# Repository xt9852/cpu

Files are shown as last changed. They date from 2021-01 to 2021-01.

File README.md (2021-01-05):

# 项目说明
- 这是一个用TTL与非门电路自制CPU项目
- 微指令结构
- 8位数据总线(BD)
- 8位地址总线(BA)
- 9个8位寄存器(RI,RF,RP,RS,RA,RB,RC,RD,RT)
- 1个8位ALU
- 目前只用Proteus做模拟

# 项目文件
|文件|说明|
|----|----|
|8bit-cpu.dsn|Proteus的模拟|
|8bit-cpu.LYT|Proteus的PCB|
|16bit-cpu.dsn|Proteus的模拟|
|doc/cpu.png|cpu逻辑架构图|
|doc/make pcb.txt|将ares转为CAM350步骤|
|doc/mi.xls|微指令详细|
|mi/mi.exe|生成微指令工具,将mi.txt转化成mi_*.bin|
|mi/MI.c|mi.exe的源代码|
|mi/mi.txt|微指令源码|
|mi/mi_*.bin|微指令|
|mi/rom.bin|内存程序|

# 逻辑结构
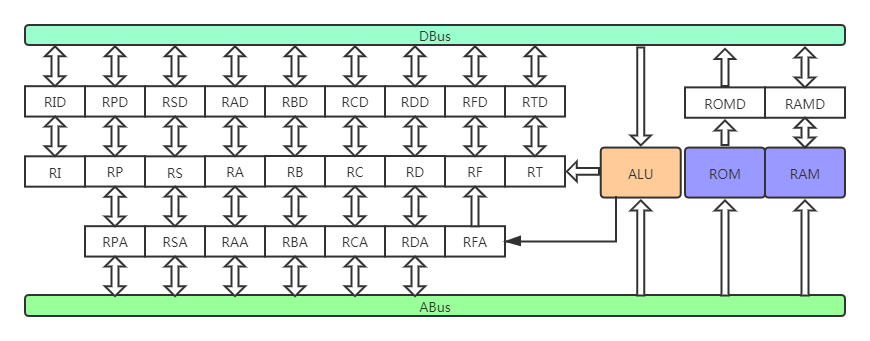
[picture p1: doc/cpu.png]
cmd-markdown-logo


# 物理结构
- 微指令驱动部分
    由AN0-1,AC0-1组成,
    由IN-CLK,SIG-CLK_信号驱动,
    主要是对微指令的当前地址进行操作

- 微指令跳转部分
    由SEL0-5组成,
    由IN-INT0-1,CHK-BI,JL,JNE信号生成的SIG-A,SIG-B信号驱动,
    主要是对微指令的下一条地址进行操作,
    通过选择不同的微指令地址以实现微指令跳转

    |SIG-B|SIG-A|说明|
    |----|----|----|
    |0|0|选取下一条地址为微指令地址|
    |0|1|选取0x[BI]0组成微指令地址|
    |1|0|选取中断微指令地址0x005|
    |1|1|选取条件跳转微指令地址0x004|
    
- 微指令存储部分
    由MI0~7组成，
    由AC[]驱动

    |微指令|说明|
    |----|----|
    |CHK-BI|选取指令寄存器做微指令地址|
    |CHK-INT|检测是否发生中断|
    |CHK-JE|检测是否等于跳转|
    |CHK-JNE|检测是否不等于跳转|
    |CHK-JB|检测是否大于跳转|
    |CHK-JBN|检测是否大于等于跳转|
    |CHK-JL|检测是否小于跳转|
    |CHK-JLN|检测是否小于等于跳转|
    |RA-A|连通A总线,0-输入,1-输出|
    |RA-RW|操作:0-读,1写|
    |RA-D|连通D总线,0-输入,1-输出|
    |ALU-S0|ALU控制S0|
    |ALU-S1|ALU控制S1|
    |ALU-S2|ALU控制S2|
    |ALU-S3|ALU控制S3|
    |ALU-M|ALU运算类型:0-算数,1-逻辑|
    |ALU-CN|ALU进位|
    |MEM-CE|内存选通|
    |MEM-RW|内存操作:0-读，1写|
    |MEM-OE|内存读操作:0-有效，1-无效|
    |MEM-WE|内存写操作:0-有效，1-无效|

- 寄存器与总线部分
    RI,RID,RF,RFA,RFD,RP,RPA,RPD,RS,RSA,RSD,
    RA,RAA,RAD,RB,RBA,RBD,RC,RCA,RCD,RD,RDA,RDD,
    RT,RTD

- ALU与临时寄存器部分
    由ALU0-1，RT组成,
    由ALU-S0-3,M,CN,RT-RW,RT-F信号驱动

- 内存部分
    由ROM,RAM,ROMD,RAMD组成,
    由BA,BD,MEM-CE,RW,OE,WE信号驱动

# 数据流
- 微指令跳转部分=>微指令驱动部分=>微指令存储部分=>寄存器与总线部分,ALU与临时寄存器部分,内存部分

# 指令执行过程
- 清空各寄存器操作
- 检测中断操作
- 取指和IP++操作
- 更新IP操作
- 执行指令操作

# 微代码说明
- [微代码详细](https://github.com/xt9852/CPU/blob/master/doc/mi.xls)

# 所用芯片
|芯片|说明|
|----|----|
|74LS04|非门|
|74LS08|2输入与门|
|74LS32|2输入或门|
|74LS138|3-8译码器|
|74LS153|双4选1选择器|
|74LS165|并入串出|
|74LS181|逻辑运算器|
|74LS245|双向驱动器|
|74LS373|寄存器|
|2732|ROM存储器,存储微指令|
|27256|ROM存储器|
|62256|RAM存储器|

# ALU逻辑
|S0|S1|S2|S3|M|Cn|功能|
|----|----|----|----|----|----|----|
|H|H|L|L|H|*|0|
|L|L|H|H|H|*|0xFF|
|H|H|H|H|H|*|A|
|H|L|H|L|H|*|B|
|L|L|L|L|H|*|A非|
|H|H|L|H|H|*|A与B|
|L|H|H|H|H|*|A或B|
|L|H|H|L|H|*|A异或B|
|H|L|L|H|L|H|A加B|
|L|H|H|L|L|L|A减B|
|L|L|L|L|L|L|A++|
|H|H|H|H|L|H|A--|

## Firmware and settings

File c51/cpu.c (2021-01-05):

//头文件:
#include <reg52.h>
#include <stdio.h>
#include "uart.h"    // 串口


// IO引脚定义
sbit DATA_IN  = P1^0;
sbit DATA_LD  = P1^1;
sbit DATA_CLK = P1^2;
sbit IN_CLK   = P1^3;

// 延时子函数,int为2个字节,long为4个字节
// 参数 time 大小决定延时时间长短
void delay(unsigned long n)
{
	n *= 10;

	while(n--); // 用于延时
}

void uart_proc(unsigned char ch, void *param)
{
    UART_send_byte(ch);
}

void save_data()
{
    DATA_LD = 0;    // save data
    delay(1);
    DATA_LD = 1;
    delay(1);
}

unsigned long get_data(unsigned int count)
{
    unsigned int i;
    unsigned long d;
    unsigned long n = 0;

    for (i = 0; i < count; i++)
    {
        d = DATA_IN;    // read data
        delay(1);
        DATA_CLK = 0;
        delay(1);
        DATA_CLK = 1;   // output data
        delay(1);
        
        n |= (d << i);
    }

    return n;
}

void get_mi()
{
    char buff[32];
    unsigned int i;
    unsigned int j;
    unsigned int k;
    unsigned int l;

    save_data();
    UART_send_string("--save--data--\r");
    
    i = get_data(12);
    sprintf(buff, "AC:      0x%03X\r", i);

    UART_send_string(buff);
    i = get_data(12);
    sprintf(buff, "AT:      0x%03X\r", i);
    UART_send_string(buff);

    i = get_data(12);
    sprintf(buff, "AN:      0x%03X\r", i);
    UART_send_string(buff);

    i = get_data(8);
    sprintf(buff, "BA:      0x%02X\r", i);
    UART_send_string(buff);

    i = get_data(8);
    sprintf(buff, "BD:      0x%02X\r", i);
    UART_send_string(buff);

    i = get_data(8);
    sprintf(buff, "BF:      0x%02X\r", i);
    UART_send_string(buff);

    i = get_data(1);
    sprintf(buff, "SIG-JL:  %d\r", i);
    UART_send_string(buff);

    i = get_data(1);
    sprintf(buff, "SIG-JNE: %d\r", i);
    UART_send_string(buff);

    i = get_data(2);
    sprintf(buff, "SIG-AB:  %d\r", i);
    UART_send_string(buff);

    i = get_data(1);
    sprintf(buff, "CHK-BI:  %d\r", i);
    UART_send_string(buff);

    i = get_data(1);
    sprintf(buff, "CHK-INT: %d\r", i);
    UART_send_string(buff);

    i = get_data(1);
    sprintf(buff, "CHK-JE:  %d\r", i);
    UART_send_string(buff);

    i = get_data(1);
    sprintf(buff, "CHK-JNE: %d\r", i);
    UART_send_string(buff);

    i = get_data(1);
    sprintf(buff, "CHK-JB:  %d\r", i);
    UART_send_string(buff);

    i = get_data(1);
    sprintf(buff, "CHK-JBE: %d\r", i);
    UART_send_string(buff);

    i = get_data(1);
    sprintf(buff, "CHK-JL:  %d\r", i);
    UART_send_string(buff);

    i = get_data(1);
    sprintf(buff, "CHK-JLE: %d\r", i);
    UART_send_string(buff);

    j = get_data(1);
    k = get_data(1);
    sprintf(buff, "RI:%s %s\r", (j==0?"R":"W"), (k==0?"DBus":""));
    UART_send_string(buff);

    i = get_data(1);
    j = get_data(1);
    k = get_data(1);
    sprintf(buff, "RF:%s %s %s\r", (j==0?"R":"W"), (k==0?"DBus":""), (i==0?"ABus":""));
    UART_send_string(buff);

    i = get_data(1);
    j = get_data(1);
    k = get_data(1);
    sprintf(buff, "RP:%s %s %s\r", (j==0?"R":"W"), (k==0?"DBus":""), (i==0?"ABus":""));
    UART_send_string(buff);

    i = get_data(1);
    j = get_data(1);
    k = get_data(1);
    sprintf(buff, "RS:%s %s %s\r", (j==0?"R":"W"), (k==0?"DBus":""), (i==0?"ABus":""));
    UART_send_string(buff);

    i = get_data(1);
    j = get_data(1);
    k = get_data(1);
    sprintf(buff, "RA:%s %s %s\r", (j==0?"R":"W"), (k==0?"DBus":""), (i==0?"ABus":""));
    UART_send_string(buff);


    i = get_data(1);
    j = get_data(1);
    k = get_data(1);
    sprintf(buff, "RB:%s %s %s\r", (j==0?"R":"W"), (k==0?"DBus":""), (i==0?"ABus":""));
    UART_send_string(buff);

    i = get_data(1);
    j = get_data(1);
    k = get_data(1);
    sprintf(buff, "RC:%s %s %s\r", (j==0?"R":"W"), (k==0?"DBus":""), (i==0?"ABus":""));
    UART_send_string(buff);


    i = get_data(1);
    j = get_data(1);
    k = get_data(1);
    sprintf(buff, "RD:%s %s %s\r", (j==0?"R":"W"), (k==0?"DBus":""), (i==0?"ABus":""));
    UART_send_string(buff);

    i = get_data(6);
    if (i == 0) sprintf(buff, "ALU:++\r");
    else if (i == 0x13) sprintf(buff, "ALU:0xFF\r", i);
    else if (i == 0x34) sprintf(buff, "ALU:0xFF\r", i);
    else sprintf(buff, "ALU:%x\r", i);
    UART_send_string(buff);

    j = get_data(1);
    k = get_data(1);
    sprintf(buff, "RT:%s %s\r", (j==0?"R":"W"), (k==0?"DBus":""));
    UART_send_string(buff);

    i = get_data(1); // M-CE
    j = get_data(1); // M-RW
    k = get_data(1); // M-OE
    l = get_data(1); // M-WE
    sprintf(buff, "MEM:%s OE:%d WE:%d\r", (i==0?(j==0?"R":"W"):""), j, k);
    UART_send_string(buff);

    i = get_data(1); // SIG-ROM
    sprintf(buff, "SIG-ROM:%d\r", i);
    UART_send_string(buff);

    i = get_data(1); // SIG-RAM
    sprintf(buff, "SIG-RAM:%d\r", i);
    UART_send_string(buff);
}

//主函数，C语言的入口函数
void main(void)
{
    unsigned int last = 1;

    UART_init(2400, uart_proc, '\n');

    while (1)
	{
        if (last == 1 && IN_CLK == 0)
        {
             get_mi();
        }

        last = IN_CLK;

        delay(10);
	}
}

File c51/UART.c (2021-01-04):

#include <reg52.h>
#include "UART.h"

#ifndef NULL
#define NULL 0
#endif


UART_PROC  g_uart_proc  = NULL;
void      *g_uart_param = NULL;


// 发送1个字符
void UART_send_byte(unsigned char ch)
{
	SBUF = ch;
	while (!TI);  // 发送中断标志位，数据发送结束时，标志位会自动置1，需要通过程序将其置0
	TI = 0;
}

// 发送字符串
void UART_send_string(char *str)
{
	while (*str != '\0')
	{
		UART_send_byte(*str++);
	}
}

// 串口中断入口函数
void UART_interrupt_func() interrupt 4
{
	if (RI)								// 接收中断标志位，数据接收结束时，标志位会自动置1
	{
		RI = 0;							// 将接收中断标志位复位等待接收下一个字节
        g_uart_proc(SBUF, g_uart_param);
	}
}

// 初始化串口中断
void UART_init(unsigned long baud, UART_PROC proc, void *param)
{
    // 串口工作方式寄存器 SCON
    //
    // 位置	    D7	D6	D5	D4	D3	D2	D1	D0
    // 功能     SM0	SM1	SM2	REN	TB8	RB8	TI	RI
    //
    // RI       接收中断标志位，数据接收结束时，标志位会自动置1，需要通过程序将其置0
    // TI       发送中断标志位，数据发送结束时，标志位会自动置1，需要通过程序将其置0
    // RB8      存放发送数据的第9位
    // TB8      存放接收数据的第9位
    // REN      串行接收允许位，0允许串行接收，1禁止串行接收
    // SM2      多机控制位
    // SM1 SM0  串行工作方式
    //
    // SM0 SM1 方式	说明	                    波特率
    // 0   0    0   移位寄存器	                晶振频率/12
    // 0   1    1   10位异步收发器（8位数据）	可变
    // 1   0    2   11位异步收发器（9位数据）	晶振频率/32或晶振频率/64
    // 1   1    3   11位异步收发器（9位数据）	可变

    // -----------------------------------------------------------------------
    // 计数器工作方式寄存器 TMOD
    //
    // 位置	    D7   D6	  D5   D4   D3   D2	  D1   D0
    // 功能	    GATE C/T  M1   M0   GATE C/T  M1   M0
    //
    // 高四位为定时计数器T1的设置，低四位是定时计数器T0设置
    //
    // C/T      定时器和计数器选择位，0-定时器，1-计数器
    // M1	M0	工作方式
    //
    // 0	0   工作方式0：为13位定时/计数器
    // 0	1	工作方式1：为16位定时/计数器
    // 1	0	工作方式2：8位初值自动重装定时/计数器
    // 1	1	工作方式3：仅适用于T0，分成两个8位计数器，T1停止计数

    // 振荡周期：也称时钟周期（频率的倒数），单片机提供时钟信号的振荡源周期，频率一般有11.0592MHz，12MHz等
    // 状态周期：是振荡周期的2倍
    // 机器周期：是包含6个状态周期，机器周期=1/单片机时钟频率
    // 单片机时钟频率：是外部时钟的12分频，如果是12MHz的晶振，机器周期=1/单片机时钟频率=1/（12MHz/12）=12/12M=1us
    // 这里一个机器周期为1us，若定时时间为1ms，则需要1000个机器周期，计算出初值；如果机器周期为2us，则只需要500个机器周期。
    // 定时器初值计算：初值=（65536-机器周期数量）
    // 波特率计算：
    // 当串口工作在工作方式0和2是，波特率固定，方式0时fosc/12;方式2时fosc/32或fosc/64（根据SMOD判断）。
    // 当串口工作在方式1时，波特率=(2^SMOD/32)*(单片机时钟频率/(256-X)),X是初值
    
    // -----------------------------------------------------------------------
    // 电源管理寄存器PCON
    //
    // 位置	    D7   D6	  D5   D4   D3   D2	  D1   D0
    // 功能	    SMOD  -	  -	   -	GF1  GF0  PD   IDL
    // 
    // SOMD     波特率是否加倍选择位，0波特率不加倍，1波特率加倍
    // GF1 GF0  通用标志位。
    // PD       掉电方式位。当PD=1 时，进入掉电方式
    // IDL      待机方式位。当IDL=1 时，进入待机方式
    //
    // 波特率不加倍时：TH1 = TL1 = 晶振值/12/2/16/波特率
    // 当波特率加倍时：TH1 = TL1 = 晶振值/12/16/波特率

    // -----------------------------------------------------------------------
    // 中断允许寄存器 IE
    //
    // 位置	    D7   D6	  D5   D4   D3   D2	  D1   D0
    // 功能	    EA   -	  -	   ES   ET1  EX1  ET0  EX0
    //
    // EA       全避中断允许位
    // ET2      定时/计数器2中断允许位
    // ES       串口中断允许位
    // ET1      定时/计数器1中断允许位
    // EX1      外部中断1允许位
    // ET0      定时/计数器0中断允许位
    // EX0      外部中断0允许位

    TMOD |= 0x20;						// 设置计数器1的工作方式为2，8位初值自动重装定时/计数器
    PCON = 0x00;						// 波特率不加倍
    SCON = 0x50;						// 设置串口工作方式为1，10位异步收发器（8位数据）

    TH1  = 256 - (12000000/12/32)/baud; // 计数器的初值,板子使用12M晶振，初值=256-12000000/12/32/波特率
	TL1  = TH1;                         // 12M的晶振波特率只能是2400，9600会有7.8%的误差，会产生乱码，而2400误差是0.16%
	   
    EA   = 1;							// 开启总中断
    ES   = 1;							// 开启串口接收中断
	TR1  = 1;							// 开启计数器

    g_uart_proc = proc;
    g_uart_param = param;
}

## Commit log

2017-08-17 update mi and msw
    [cpu.dsn, mi.xls]
2020-04-06 + 16bit-cpu # mi
    [16bit-cpu.dsn, mi.xls]
2020-04-06 # <<,>>,INT,MI
    [16bit-cpu.dsn, mi.xls]
2020-04-06 # MI
    [16bit-cpu.dsn, mi.xls]
2021-01-02 add 74ls165
    [8bit-cpu.dsn, mi.xls]
2021-01-02 update readme.md and cpu.png
    [8bit-cpu.dsn, mi.xls]
2021-01-02 del TR-F
    [8bit-cpu.dsn]
2021-01-02 update NodeMCU connect
    [8bit-cpu.dsn]
2021-01-04 add 80c51,del tr-a
    [8bit-cpu.dsn, mi.xls]
2021-01-05 rename all ic
    [8bit-cpu.dsn, mi.xls]
